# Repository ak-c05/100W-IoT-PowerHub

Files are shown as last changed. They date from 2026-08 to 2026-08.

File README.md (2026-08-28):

# 100W IoT Power Hub | ESP32-C3

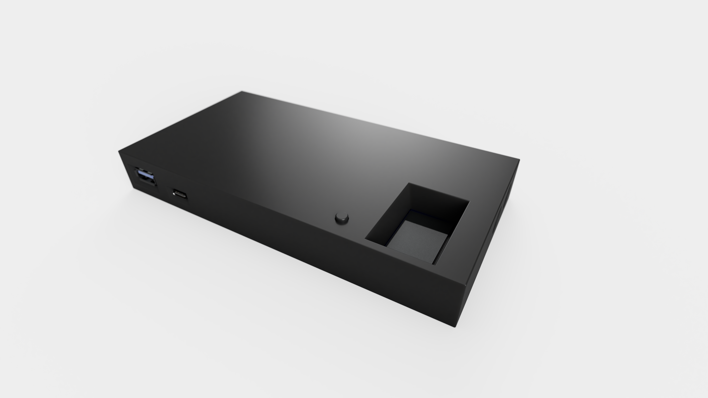
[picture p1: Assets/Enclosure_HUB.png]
Hero Render


A custom-engineered, dual-rail Power Delivery (PD) hub featuring hardware-level I2C telemetry, commercial DFM clamshell mechanics, and an asynchronous WebSocket control dashboard. 

---

## Mechanical Engineering (DFM)

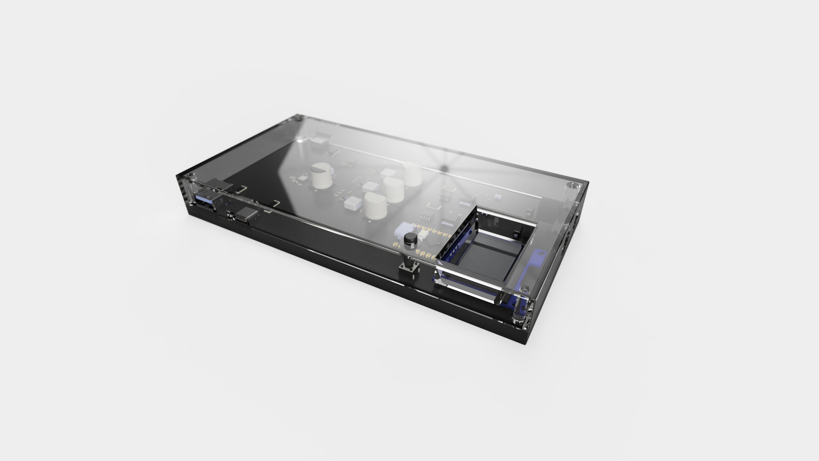
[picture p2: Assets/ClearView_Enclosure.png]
Internal Architecture


The enclosure is architected for a friction-fit prototyping phase, scaling to ultrasonic welding for mass production.
* **Non-Collision Assembly:** Designed with strict vertical U-channels for all I/O ports, eliminating plastic undercuts and allowing seamless top-down Z-axis assembly.
* **Interference Tolerancing:** Utilizes a modeled `0.05mm` press-pull lip-and-groove parting line to achieve a reliable friction fit without failure-prone snap hooks.
* **Kinematic Trapping:** The PCB is cradled by lower bosses and secured by mirrored upper retaining posts featuring a `0.2mm` rattle gap to guarantee closure without crushing the FR4 fiberglass.
* **Captive Actuation:** Features a custom 15mm "long-stem mushroom" plunger mechanism with strict 0.2mm clearance tolerances for the tactile UI switch.

---

## Electrical Architecture

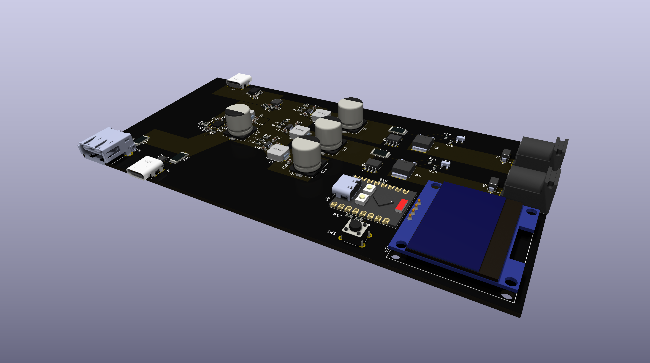
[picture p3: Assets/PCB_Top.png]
PCBA Render Top

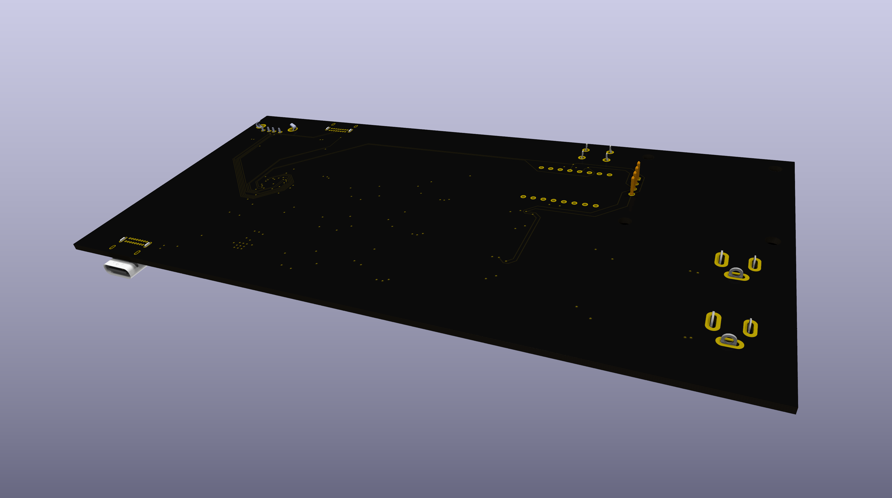
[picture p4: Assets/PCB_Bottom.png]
PCBA Render Bottom


Designed in KiCad 7/8, the motherboard isolates high-power delivery protocols from sensitive RF and logic components.
* **Dual-Rail Telemetry:** Utilizes two Texas Instruments INA219 ICs (I2C) for independent, high-speed monitoring of both the 12V Main and 9V PD lines.
* **Hardware PD Negotiation:** Integrates the autonomous SW3516 buck-boost controller for dedicated Type-C PD 3.0 protocol handshakes, offloading thermal and negotiation logic from the MCU.
* **RF Isolation:** Antenna routing and component placement are optimized to prevent the ESP32-C3's 2.4GHz radio from introducing jitter into the analog-to-digital current sensing pathways.

---

## Embedded Firmware & IoT

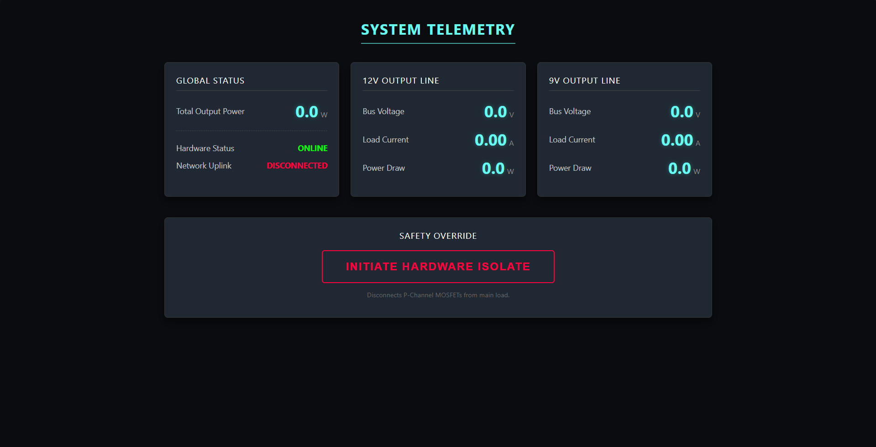
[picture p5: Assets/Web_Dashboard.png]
Web Dashboard


The C++ backend operates on a strict, non-blocking deterministic state machine, ensuring network handling never interrupts safety-critical hardware isolation.
* **Asynchronous WebSockets:** The ESP32 hosts a continuous WebSocket tunnel, pushing serialized JSON packets to the frontend only when clients are actively connected, saving CPU cycles.
* **PROGMEM Decoupling:** All HTML, CSS, and JavaScript assets are decoupled into an external `dashboard.h` file and stored in flash memory, preserving SRAM for runtime telemetry.
* **Hardware-Agnostic Graphics:** Drives a 1.3" SH1106 OLED using the U8g2 memory buffer, pushing mathematical frame geometry in single I2C blasts to prevent screen tearing.
* **Zero-Blocking Safety:** The 20-millisecond overcurrent protection polling loop runs independently of the network stack; physical hardware isolation always overrides remote UI commands.

---

## Future Roadmap
* Implementation of `WiFiManager` (Captive Portal) for dynamic AP provisioning, removing hardcoded network credentials from the master branch.

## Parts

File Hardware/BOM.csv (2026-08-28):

Reference | Qty | Value | Footprint | MANUFACTURER | MP
C1,C6,C12,C18,C22,C23 | 6 | 0.1uF | Capacitor_SMD:C_0603_1608Metric | Generic
C2 | 1 | 0.01uF | Capacitor_SMD:C_0603_1608Metric | Generic
C3 | 1 | 0.047uF | Capacitor_SMD:C_0603_1608Metric | Generic
C4,C5,C10,C11,C16,C17,C24 | 7 | 10uF | Capacitor_SMD:C_0603_1608Metric | Generic
C7,C8,C13,C14,C19,C20,C28,C29 | 8 | 22uF | Capacitor_SMD:C_0603_1608Metric | Generic
C9,C15,C21 | 3 | 470uF 35V | Capacitor_SMD:CP_Elec_10x10.5 | Generic
C25 | 1 | 1uF | Capacitor_SMD:C_0603_1608Metric | Generic
C26 | 1 | 2.2uF | Capacitor_SMD:C_0603_1608Metric | Generic
C27 | 1 | 10nF | Capacitor_SMD:C_0603_1608Metric | Generic
C30 | 1 | 220uF 35V | Capacitor_SMD:CP_Elec_10x10.5 | Generic
D1 | 1 | TVS(SMAJ13A) | DigitalHUB:TVS13(DIOM4325X250N) | Taiwan Semiconductor | SMAJ13A
D2 | 1 | TVS(SMAJ10A) | DigitalHUB:TVS10(DIOM4325X250N) | Taiwan Semiconductor | SMAJ10A
DS1 | 1 | OLED_128X64_1.3_I2C | DigitalHUB:LCD_OLED_128X64_1.3_I2C | UNIVERSAL-SOLDER Electronics Ltd | OLED 128x64 1.3"; I2C
J1,J4 | 2 | USB_C(USB4920-00-A_REVA) | DigitalHUB:USB_C(GCT_USB4920-00-A_REVA) | Global Connector Technology | USB4920-00-A
J2,J3 | 2 | DC_Plug(PJ-002AH) | DigitalHUB:DC_Plug(CUI_PJ-002AH) | CUI INC | PJ-002AH
J5 | 1 | USB_A(614004190021) | DigitalHUB:USB_A(614004190021) | Würth Elektronik | 614004190021
L1,L2,L3,L4 | 4 | 10uH | DigitalHUB:Inductor(WE-LHMI_7030) | Würth Elektronik | 74437346100
Q1,Q4 | 2 | MOSFET(AOD4185) | DigitalHUB:MOSFET(AOD4185) | Alpha & Omega | AOD4185
Q2,Q3 | 2 | NPN(MMBT3904) | DigitalHUB:NPN(MMBT3904) | Diotec Semiconductor | MMBT3904
Q5,Q6,Q7,Q8 | 4 | N-MOSFET(AON7400A) | DigitalHUB:TRANS_AON7407 | Alpha & Omega | AON7400A
R1,R9 | 2 | 140K | Resistor_SMD:R_0603_1608Metric | Generic
R2,R6,R7,R10,R15,R18,R21,R22,R23,R24,R25 | 11 | 10K | Resistor_SMD:R_0603_1608Metric | Generic
R3 | 1 | 301R | Resistor_SMD:R_0603_1608Metric | Generic
R4,R8,R11 | 3 | 100K | Resistor_SMD:R_0603_1608Metric | Generic
R5 | 1 | 191K | Resistor_SMD:R_0603_1608Metric | Generic
R12 | 1 | 75K | Resistor_SMD:R_0603_1608Metric | Generic
R13,R14 | 2 | 4.7K | Resistor_SMD:R_0603_1608Metric | Generic
R16,R17,R26,R27 | 4 | 0.01R 2W 1% | Resistor_SMD:R_2512_6332Metric | Generic
R19,R20 | 2 | 1K | Resistor_SMD:R_0603_1608Metric | Generic
SW1 | 1 | SW_Push | Button_Switch_THT:SW_PUSH_6mm_H5mm | Generic
SW2 | 1 | SW3516 | DigitalHUB:QFN-28_L4.0-W4.0-P0.40-BL-EP | Ismartware | SW3516
U1 | 1 | CH224K | Package_SO:SSOP-10-1EP_3.9x4.9mm_P1mm_EP2.1x3.3mm | WCH | CH224K
U2 | 1 | E_Fuse(TPS259827ONRGET) | DigitalHUB:E_Fuse(IC_TPS259827ONRGET) | Texas Instruments | TPS259827ONRGET
U3,U4,U5 | 3 | Buck(TPS54302DDCR) | DigitalHUB:Buck(SOT95P280X110-6N) | Texas Instruments | TPS54302DDCR
U6 | 1 | ESP32-C3_SUPERMINI_TH | DigitalHUB:MODULE_ESP32-C3_SUPERMINI_TH | Espressif Systems | ESP32-C3 SuperMini_TH
U7,U8 | 2 | Vtg_Sensor(INA219AIDR) | DigitalHUB:Vtg_Sensor(INA219AIDR) | Texas Instruments | INA219AIDR

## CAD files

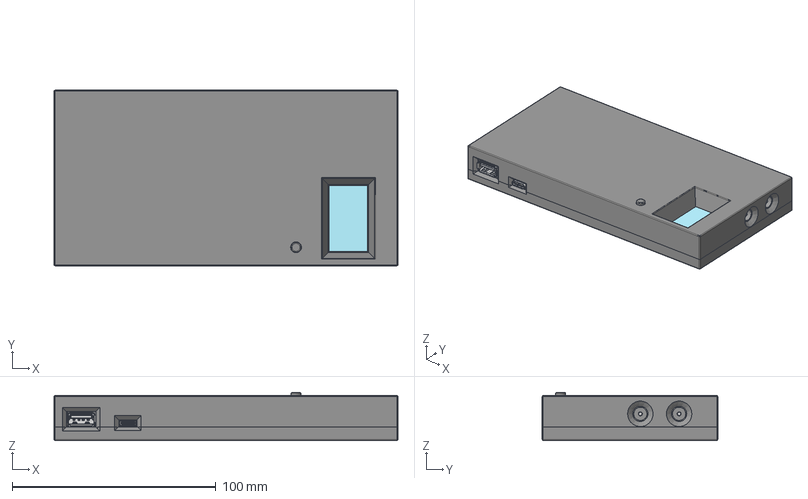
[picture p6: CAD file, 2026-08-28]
Mechanical/Digital_HUB_Master_Assembly_v2.step
168.8 x 86.1 x 23.6 mm
Bottom_Shell
R_2512_6332Metric x 4
C_0603_1608Metric x 26
SW_PUSH_6mm_h5mm_1
CP_Elec_10x105 x 4
pin x 4

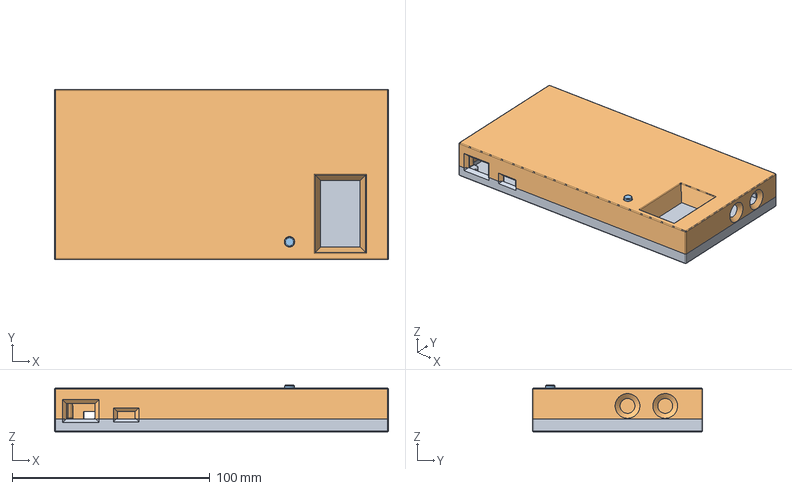
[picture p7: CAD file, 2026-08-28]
Mechanical/Digital_HUB_Plastics_Only_MFG_v2.step
168.8 x 86.1 x 23.6 mm

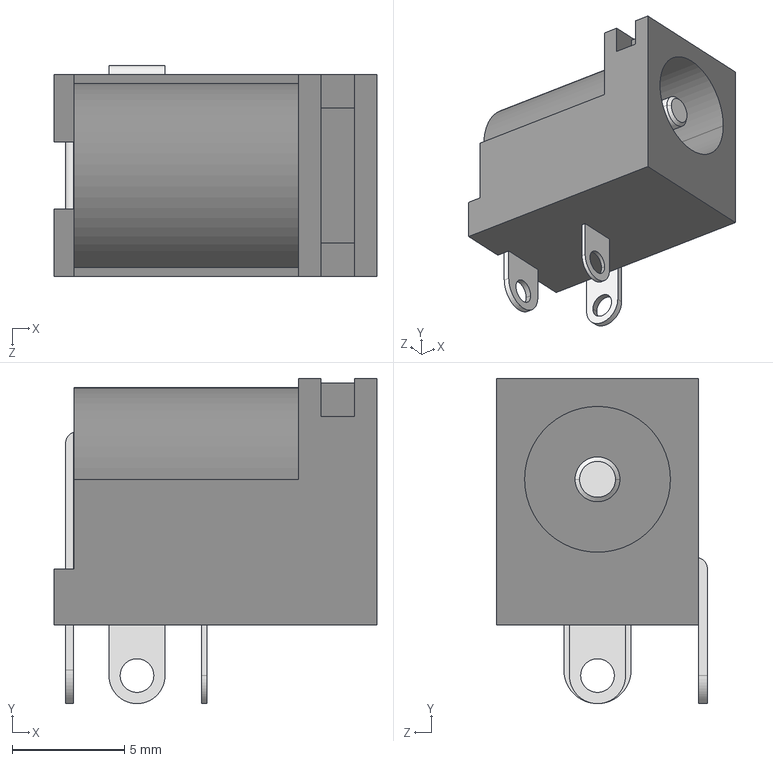
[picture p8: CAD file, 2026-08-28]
Hardware/Project_Libs/DigitalHUB_3D_Models/PJ-002AH.step
14.4 x 14.5 x 9.40 mm

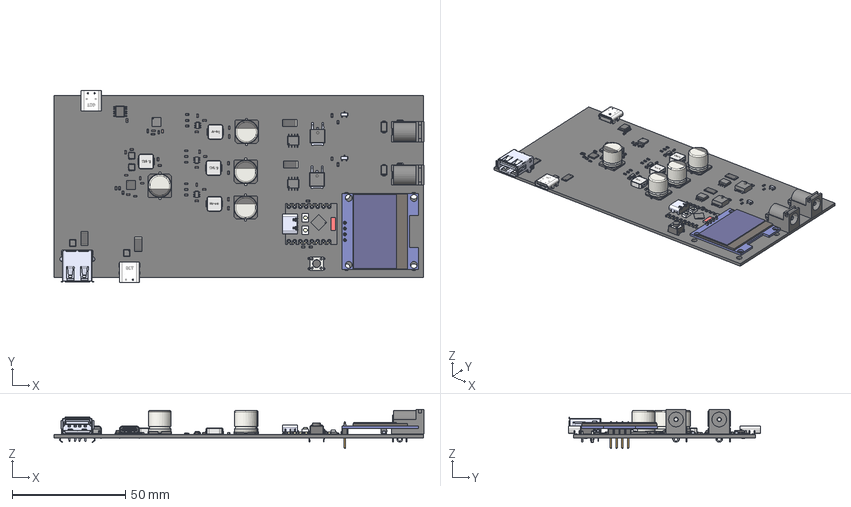
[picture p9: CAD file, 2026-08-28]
Mechanical/Digital_Hub_PCB.step
163.1 x 84.8 x 17.4 mm
R_0603_1608Metric x 23
R_2512_6332Metric x 4
C_0603_1608Metric x 26
SW_PUSH_6mm_h5mm
CP_Elec_10x105 x 4
CUI_DEVICES_PJ-002AH x 2
pin x 4
base x 4
AOD403 x 2
AON7522E x 4
MMBT3904--3DModel-STEP-711646 x 2
DDC6 x 3
SSOP-10-1EP_3.9x4.9mm_P1mm_EP2.1x3.3mm
PIN HEADER MALE 2.54MM P4
4 lü Lehim v2
Board c3mini
USB C
components (other)^ESP32-C3 SuperMini
1PGSMA110Z x 2
Cover
Internal Part
Pin
QFN-28_L4.0-W4.0-H0.9-P0.40-BL-EP
USB4920-00-A_PART1 x 2
USB4920-00-A_PART2 x 2
USB4920-00-A_PART3 x 2
USB4920-00-A_PART4 x 2
Body001 (Mirror #1) x 8
XY-plane x 24
X-axis x 24
RGE24
Digital_HUB_PCB

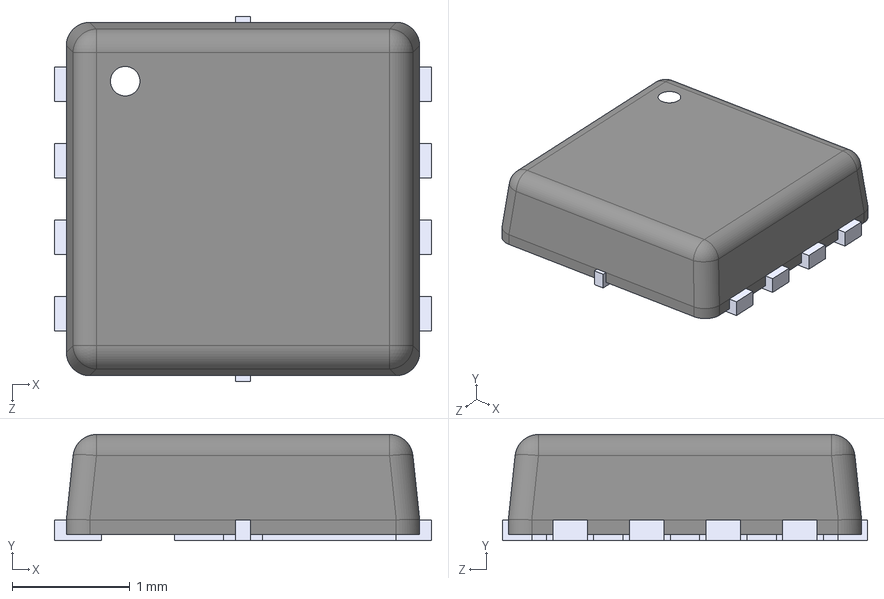
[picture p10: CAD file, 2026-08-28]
Hardware/Project_Libs/DigitalHUB_3D_Models/AON7400A.STEP
3.20 x 0.9 x 3.10 mm

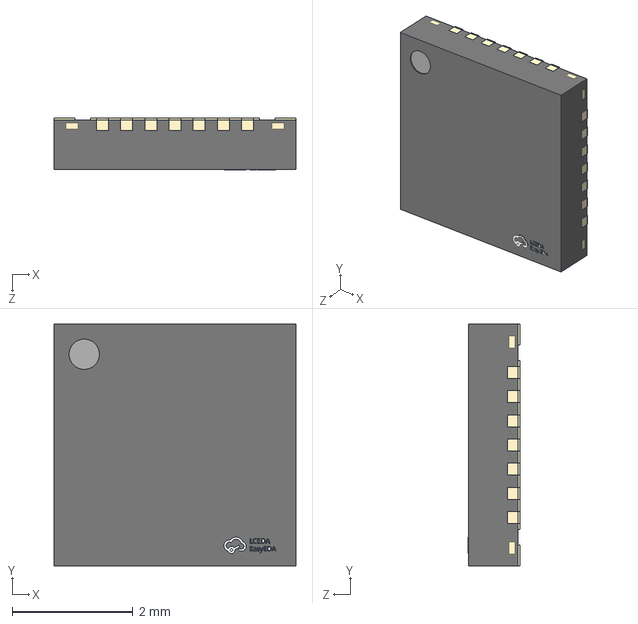
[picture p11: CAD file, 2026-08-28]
Hardware/Project_Libs/DigitalHUB_3D_Models/QFN-28_L4.0-W4.0-H0.9-P0.40-BL-EP.step
4.00 x 4.00 x 0.86 mm

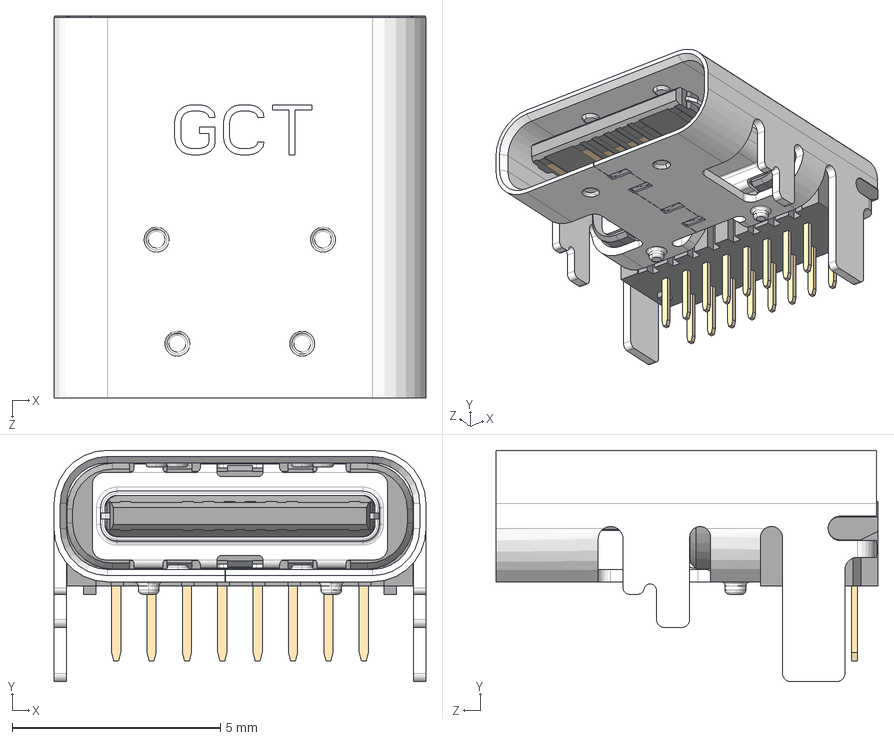
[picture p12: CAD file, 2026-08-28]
Hardware/Project_Libs/DigitalHUB_3D_Models/USB4920-00-A.stp
8.94 x 5.56 x 9.17 mm
USB4920-00-A_PART1
USB4920-00-A_PART2
USB4920-00-A_PART3
USB4920-00-A_PART4

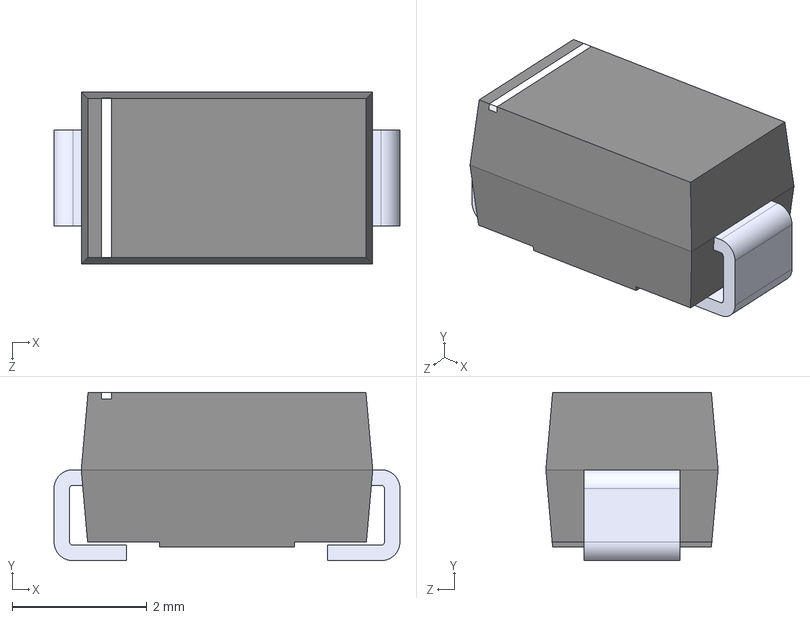
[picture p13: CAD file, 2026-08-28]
Hardware/Project_Libs/DigitalHUB_3D_Models/SMAJ10A.step
5.14 x 2.50 x 2.56 mm

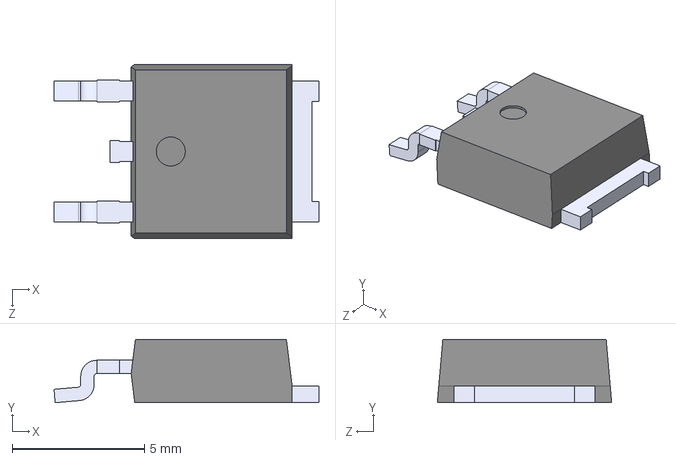
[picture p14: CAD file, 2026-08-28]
Hardware/Project_Libs/DigitalHUB_3D_Models/AOD4185.step
10.0 x 2.40 x 6.60 mm

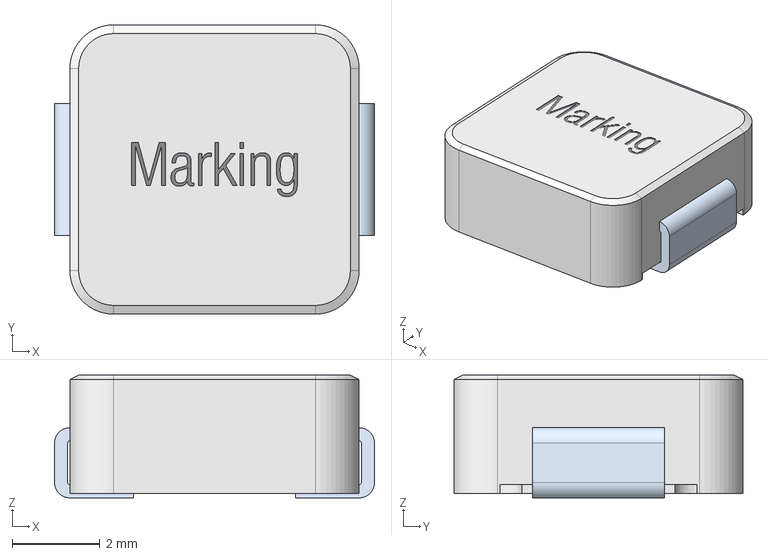
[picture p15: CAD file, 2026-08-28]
Hardware/Project_Libs/DigitalHUB_3D_Models/WE-LHMI_7030+%28rev1%29.stp
7.30 x 6.60 x 2.80 mm

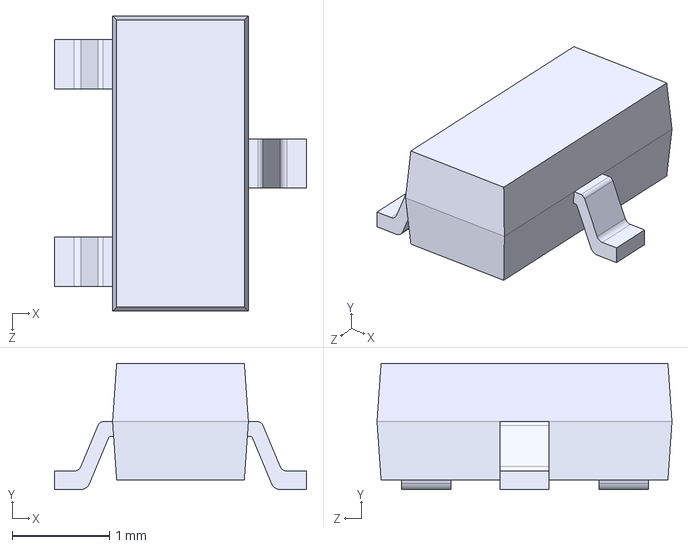
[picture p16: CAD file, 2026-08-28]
Hardware/Project_Libs/DigitalHUB_3D_Models/MMBT3904.step
2.60 x 1.30 x 3.04 mm

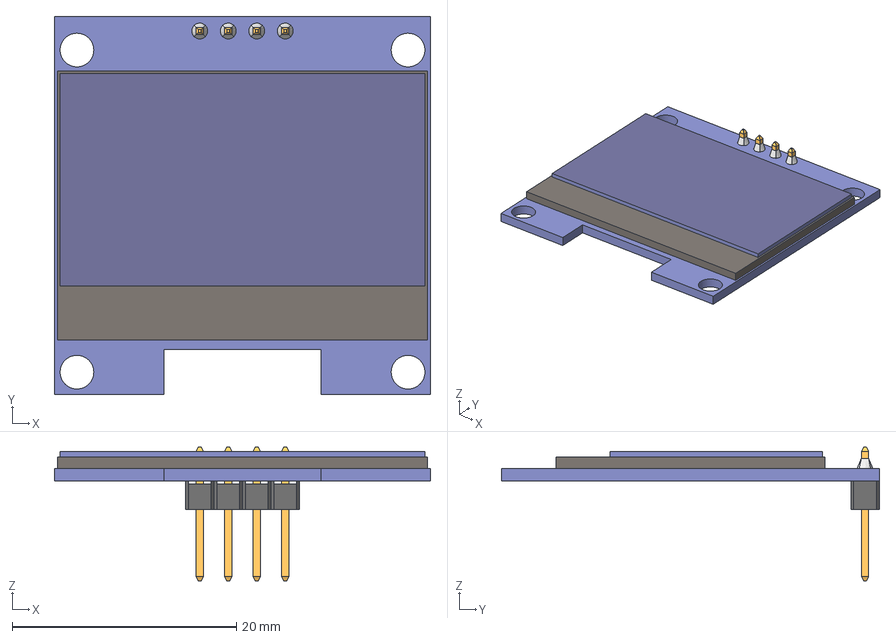
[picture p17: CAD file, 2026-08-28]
Hardware/Project_Libs/DigitalHUB_3D_Models/OLED I2C 1.3 Inch.step
33.5 x 33.7 x 11.9 mm
PIN HEADER MALE 2.54MM P4
4 lü Lehim v2

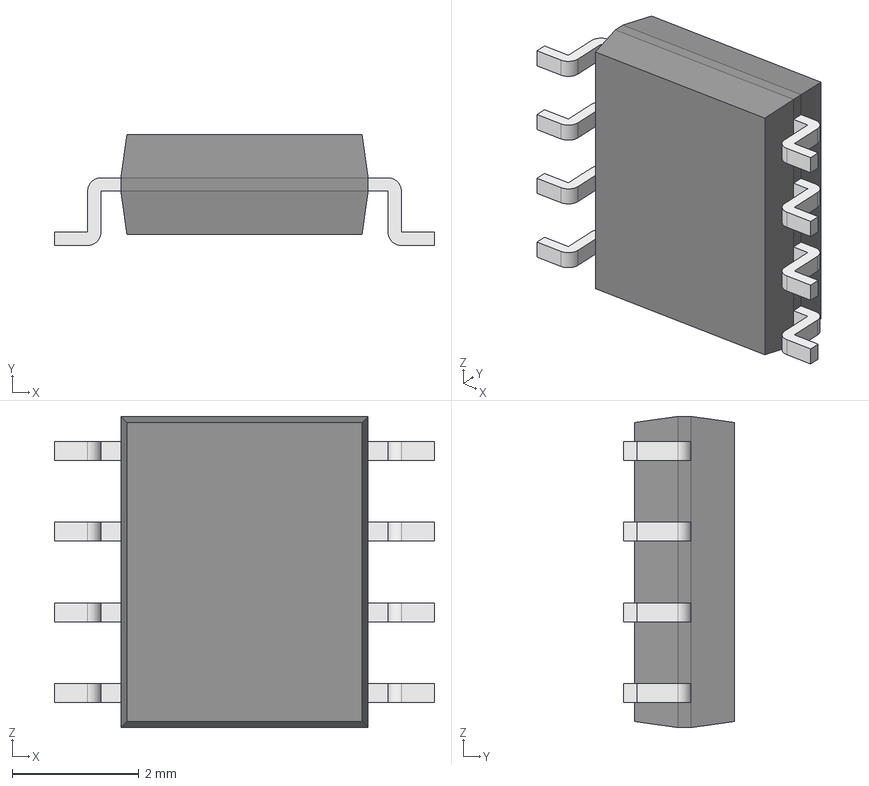
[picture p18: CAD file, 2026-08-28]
Hardware/Project_Libs/DigitalHUB_3D_Models/INA219AIDR.step
5.99 x 1.75 x 4.91 mm
Body001 (Mirror #1) x 4
XY-plane x 12
X-axis x 12

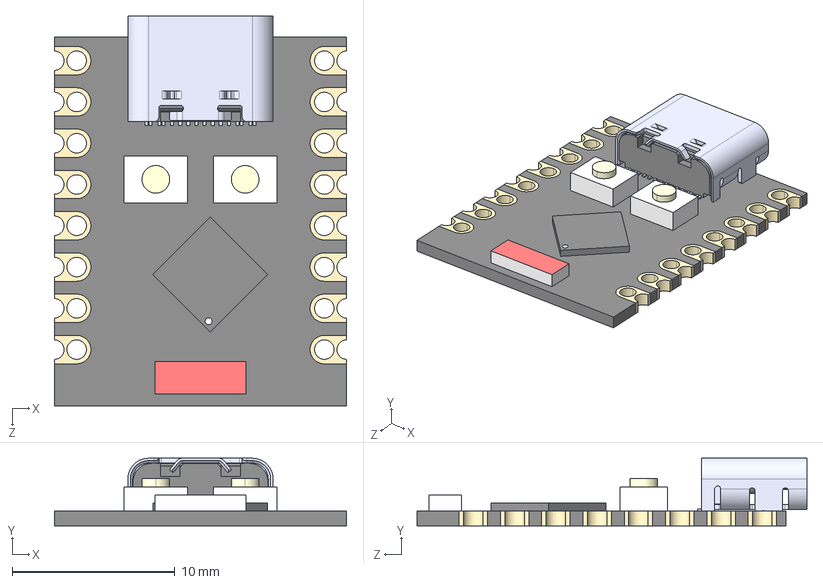
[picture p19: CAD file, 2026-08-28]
Hardware/Project_Libs/DigitalHUB_3D_Models/ESP32-C3_SUPERMINI_TH.step
18.0 x 4.16 x 24.0 mm
Board c3mini
USB C
components (other)^ESP32-C3 SuperMini

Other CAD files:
Hardware/Project_Libs/DigitalHUB_3D_Models/TPS259827ONRGET.step
Hardware/Project_Libs/DigitalHUB_3D_Models/614004190021.stp
Hardware/Project_Libs/DigitalHUB_3D_Models/TPS54302DDCR.step
Mechanical/Digital_HUB_Parametric_Archive_v2.f3z

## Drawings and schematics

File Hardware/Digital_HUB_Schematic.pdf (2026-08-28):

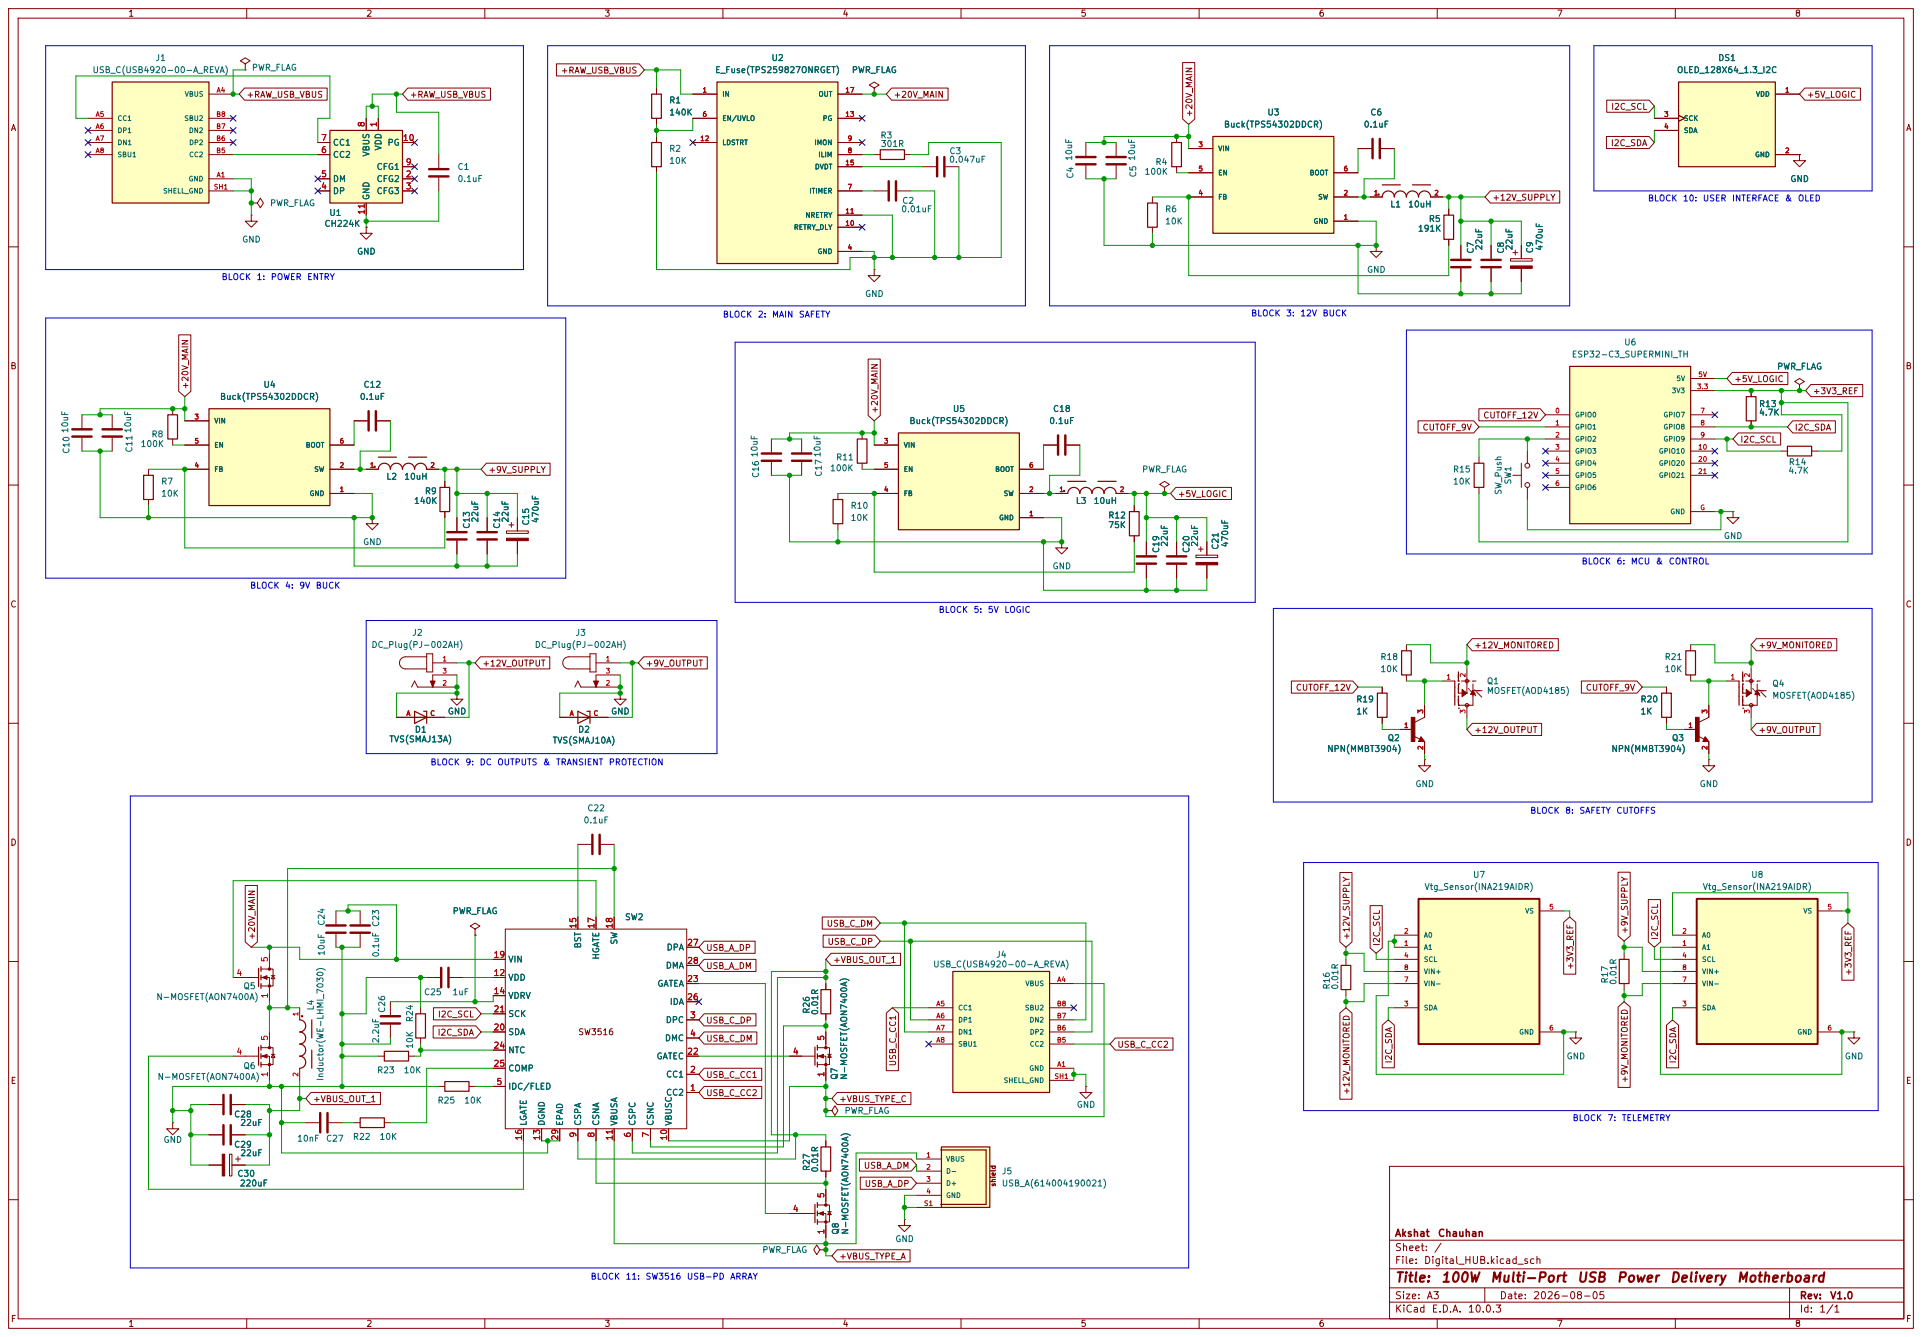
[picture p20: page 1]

BLOCK 6: MCU & CONTROL BLOCK 10: USER INTERFACE & OLED

IDA 26 DPA 27 DMA 28 EPAD 29 GND

USB_C_CC2 USB_C_CC1 BLOCK 9: DC OUTPUTS & TRANSIENT PROTECTION

IDA 26 DPA 27 DMA 28 EPAD 29

7 CSNA 8 CSPA 9 VBUSC 10 VBUSA 11

Akshat Chauhan
Sheet: /
File: Digital_HUB.kicad_sch
Title: 100W Multi-Port USB Power Delivery Motherboard

BLOCK 11: SW3516 USB-PD ARRAY

Size: A3 | Rev: V1.0 | F Date: 2026-08-05
KiCad E.D.A. 10.0.3 | Id: 1/1

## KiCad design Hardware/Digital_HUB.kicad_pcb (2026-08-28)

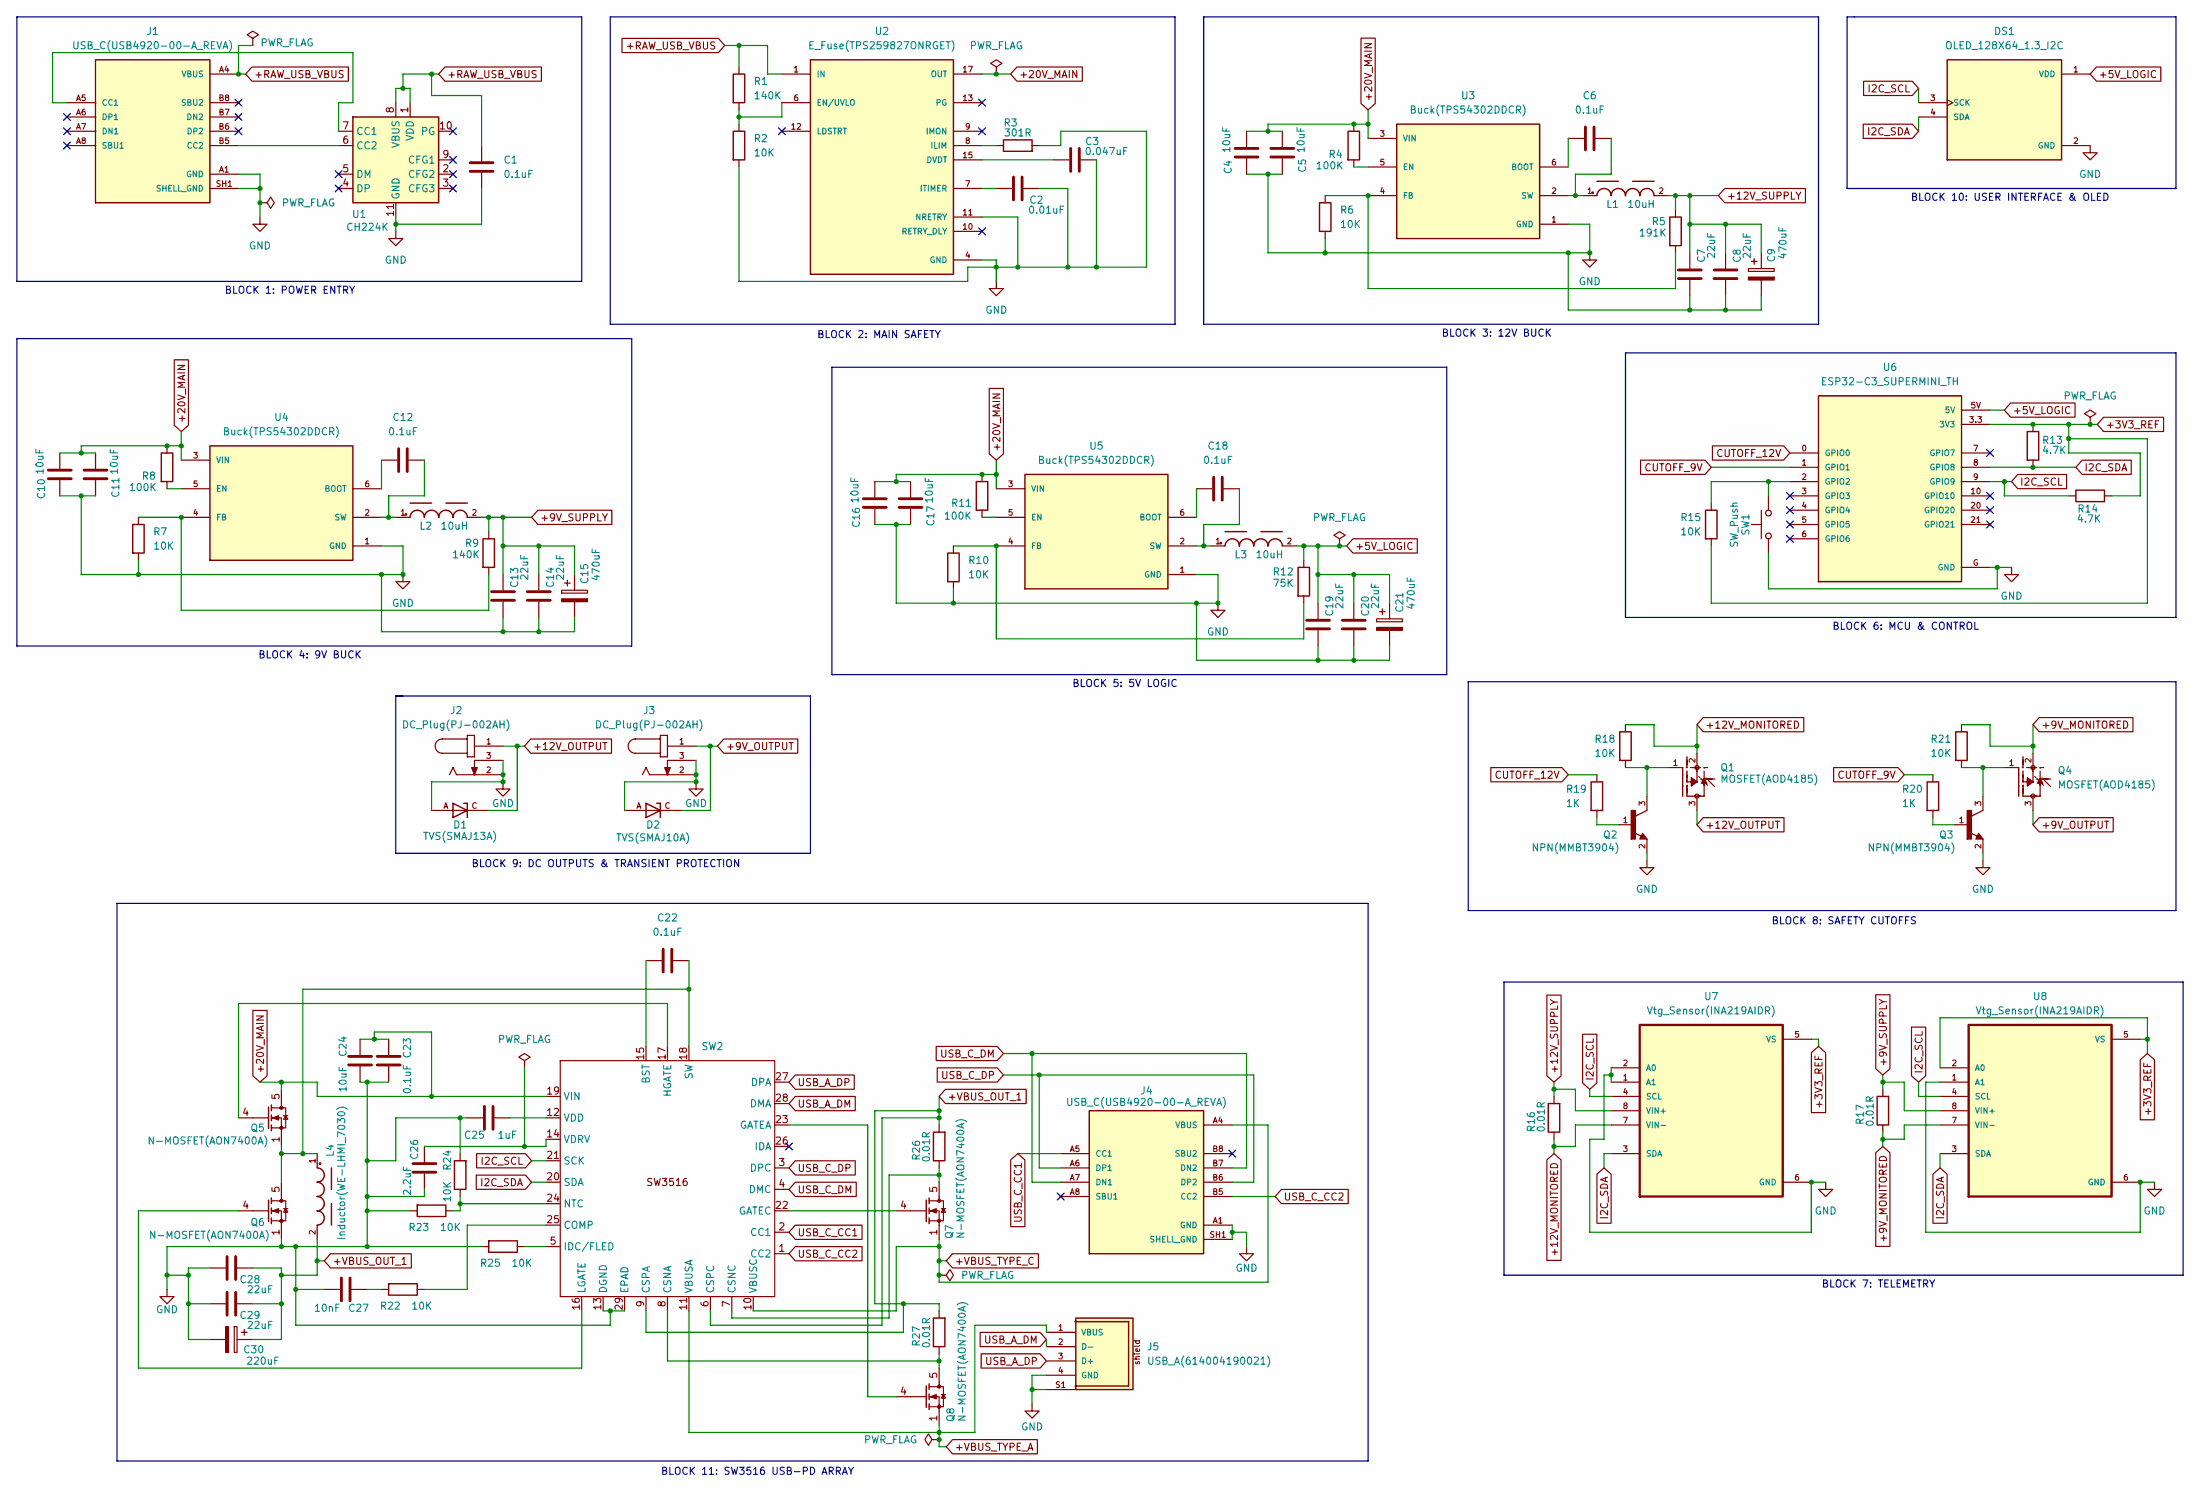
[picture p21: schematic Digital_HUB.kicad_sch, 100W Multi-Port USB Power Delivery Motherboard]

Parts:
C1, C6, C12, C18, C22, C23: 0.1uF; C_0603_1608Metric
C2: 0.01uF; C_0603_1608Metric
C3: 0.047uF; C_0603_1608Metric
C4, C5, C10, C11, C16, C17, C24: 10uF; C_0603_1608Metric
C7, C8, C13, C14, C19, C20, C28, C29: 22uF; C_0603_1608Metric
C9, C15, C21: 470uF; CP_Elec_10x10.5
C25: 1uF; C_0603_1608Metric
C26: 2.2uF; C_0603_1608Metric
C27: 10nF; C_0603_1608Metric
C30: 220uF; CP_Elec_10x10.5
D1: TVS(SMAJ13A); TVS13(DIOM4325X250N); PARTREV S2102
D2: TVS(SMAJ10A); TVS10(DIOM4325X250N); PARTREV S2102
DS1: OLED_128X64_1.3_I2C; LCD_OLED_128X64_1.3_I2C; PARTREV NA
J1, J4: USB_C(USB4920-00-A_REVA); USB_C(GCT_USB4920-00-A_REVA); PARTREV A
J2, J3: DC_Plug(PJ-002AH); DC_Plug(CUI_PJ-002AH)
J5: USB_A(614004190021)
L1, L2, L3: 10uH; Inductor(WE-LHMI_7030)
L4: Inductor(WE-LHMI_7030)
Q1, Q4: MOSFET(AOD4185)
Q2, Q3: NPN(MMBT3904); PARTREV 2025-06-30
Q5, Q6, Q7, Q8: N-MOSFET(AON7400A); TRANS_AON7407
R1, R9: 140K; R_0603_1608Metric
R2, R6, R7, R10, R15, R18, R21, R22, R23, R24, R25: 10K; R_0603_1608Metric
R3: 301R; R_0603_1608Metric
R4, R8, R11: 100K; R_0603_1608Metric
R5: 191K; R_0603_1608Metric
R12: 75K; R_0603_1608Metric
R13, R14: 4.7K; R_0603_1608Metric
R16, R17, R26, R27: 0.01R; R_2512_6332Metric
R19, R20: 1K; R_0603_1608Metric
SW1: SW_Push; SW_PUSH_6mm_H5mm
SW2: QFN-28_L4.0-W4.0-P0.40-BL-EP
U1: CH224K; SSOP-10-1EP_3.9x4.9mm_P1mm_EP2.1x3.3mm
U2: E_Fuse(TPS259827ONRGET); E_Fuse(IC_TPS259827ONRGET); PARTREV C
U3, U4, U5: Buck(TPS54302DDCR); Buck(SOT95P280X110-6N); PARTREV A
U6: ESP32-C3_SUPERMINI_TH; MODULE_ESP32-C3_SUPERMINI_TH
U7, U8: Vtg_Sensor(INA219AIDR)

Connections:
+3V3_REF: R13.1, R14.2, R15.2, U6.3.3 (3V3), U7.5 (VS), U8.2 (A0), U8.5 (VS)
+5V_LOGIC: C19.2, C20.2, C21.1, DS1.1 (VDD), L3.2, R12.1, U6.5V
+9V_MONITORED: Q4.2, R17.1, R21.1, U8.7 (VIN-)
+9V_OUTPUT: D2.C, J3.1, Q4.3
+9V_SUPPLY: C13.2, C14.2, C15.1, L2.2, R9.1, R17.2, U8.8 (VIN+)
+12V_MONITORED: Q1.2, R16.1, R18.1, U7.7 (VIN-)
+12V_OUTPUT: D1.C, J2.1, Q1.3
+12V_SUPPLY: C7.2, C8.2, C9.1, L1.2, R5.1, R16.2, U7.8 (VIN+)
+20V_MAIN: C4.2, C5.2, C10.2, C11.2, C16.2, C17.2, C23.1, C24.1, Q5.5 (D), Q5.6 (D), Q5.7 (D), Q5.8 (D), R4.1, R8.1, R11.1, SW2.19 (VIN), U2.17 (OUT), U2.18 (OUT), U2.19 (OUT), U2.20 (OUT), U2.21 (OUT), U2.22 (OUT), U2.23 (OUT), U2.24 (OUT), U3.3 (VIN), U4.3 (VIN), U5.3 (VIN)
+RAW_USB_VBUS: C1.1, J1.A4 (VBUS), J1.A9 (VBUS), J1.B4 (VBUS), J1.B9 (VBUS), R1.1, U1.1 (VDD), U1.8 (VBUS), U2.1 (IN), U2.2 (IN), U2.3 (IN), U2.16 (IN), U2.25 (IN)
+VBUS_OUT_1: C28.2, C29.2, C30.1, L4.2, R26.2, R27.2, SW2.6 (CSPC), SW2.9 (CSPA)
+VBUS_TYPE_A: J5.1 (VBUS), Q8.1 (S), Q8.2 (S), Q8.3 (S), SW2.11 (VBUSA)
+VBUS_TYPE_C: J4.A4 (VBUS), J4.A9 (VBUS), J4.B4 (VBUS), J4.B9 (VBUS), Q7.1 (S), Q7.2 (S), Q7.3 (S), SW2.10 (VBUSC)
CUTOFF_9V: R20.1, U6.1 (GPIO1)
CUTOFF_12V: R19.1, U6.0 (GPIO0)
GND: C1.2, C2.2, C3.2, C4.1, C5.1, C7.1, C8.1, C9.2, C10.1, C11.1, C13.1, C14.1, C15.2, C16.1, C17.1, C19.1, C20.1, C21.2, C23.2, C24.2, C25.1, C26.2, C27.2, C28.1, C29.1, C30.2, D1.A, D2.A, DS1.2 (GND), J1.A1 (GND), J1.A12 (GND), J1.B1 (GND), J1.B12 (GND), J1.SH1 (SHELL_GND), J1.SH2 (SHELL_GND), J1.SH3 (SHELL_GND), J1.SH4 (SHELL_GND), J2.2, J2.3, J3.2, J3.3, J4.A1 (GND), J4.A12 (GND), J4.B1 (GND), J4.B12 (GND), J4.SH1 (SHELL_GND), J4.SH2 (SHELL_GND), J4.SH3 (SHELL_GND), J4.SH4 (SHELL_GND), J5.4 (GND), J5.S1, J5.S2, Q2.2, Q3.2, Q6.1 (S), Q6.2 (S), Q6.3 (S), R2.2, R3.2, R6.2, R7.2, R10.2, R23.2, R24.2, R25.2, SW1.1, SW2.13 (DGND), SW2.29 (EPAD), U1.11 (GND), U2.4 (GND), U2.5 (GND), U2.11 (NRETRY), U2.14 (GND), U2.26 (GND), U3.1 (GND), U4.1 (GND), U5.1 (GND), U6.G (GND), U7.1 (A1), U7.2 (A0), U7.6 (GND), U8.1 (A1), U8.6 (GND)
I2C_SCL: DS1.3 (SCK), R14.1, SW2.21 (SCK), U6.9 (GPIO9), U7.4 (SCL), U8.4 (SCL)
I2C_SDA: DS1.4 (SDA), R13.2, SW2.20 (SDA), U6.8 (GPIO8), U7.3 (SDA), U8.3 (SDA)
unnamed: C27.1, R22.2
unnamed: J1.A5 (CC1), U1.7 (CC1)
unnamed: J1.B5 (CC2), U1.6 (CC2)
unnamed: Q1.1, Q2.3, R18.2
unnamed: Q2.1, R19.2
unnamed: Q3.1, R20.2
unnamed: Q3.3, Q4.1, R21.2
unnamed: Q5.4 (G), SW2.17 (HGATE)
unnamed: Q6.4 (G), SW2.16 (LGATE)
unnamed: Q7.4 (G), SW2.22 (GATEC)
unnamed: Q8.4 (G), SW2.23 (GATEA)
unnamed: C22.1, SW2.15 (BST)
unnamed: R22.1, SW2.25 (COMP)
unnamed: Q8.5 (D), Q8.6 (D), Q8.7 (D), Q8.8 (D), R27.1, SW2.8 (CSNA)
unnamed: Q7.5 (D), Q7.6 (D), Q7.7 (D), Q7.8 (D), R26.1, SW2.7 (CSNC)
unnamed: R25.1, SW2.5 (IDC/FLED)
unnamed: R23.1, R24.1, SW2.24 (NTC)
unnamed: C22.2, L4.1, Q5.1 (S), Q5.2 (S), Q5.3 (S), Q6.5 (D), Q6.6 (D), Q6.7 (D), Q6.8 (D), SW2.18 (SW)
unnamed: C25.2, SW2.12 (VDD)
unnamed: C26.1, SW2.14 (VDRV)
unnamed: C3.1, U2.15 (DVDT)
unnamed: R1.2, R2.1, U2.6 (EN/UVLO)
unnamed: R3.1, U2.8 (ILIM)
unnamed: C2.1, U2.7 (ITIMER)
unnamed: C6.1, U3.6 (BOOT)
unnamed: R4.2, U3.5 (EN)
unnamed: R5.2, R6.1, U3.4 (FB)
unnamed: C6.2, L1.1, U3.2 (SW)
unnamed: C12.1, U4.6 (BOOT)
unnamed: R8.2, U4.5 (EN)
unnamed: R7.1, R9.2, U4.4 (FB)
unnamed: C12.2, L2.1, U4.2 (SW)
unnamed: C18.1, U5.6 (BOOT)
unnamed: R11.2, U5.5 (EN)
unnamed: R10.1, R12.2, U5.4 (FB)
unnamed: C18.2, L3.1, U5.2 (SW)
unnamed: R15.1, SW1.2, U6.2 (GPIO2)
USB_A_DM: J5.2 (D-), SW2.28 (DMA)
USB_A_DP: J5.3 (D+), SW2.27 (DPA)
USB_C_CC1: J4.A5 (CC1), SW2.2 (CC1)
USB_C_CC2: J4.B5 (CC2), SW2.1 (CC2)
USB_C_DM: J4.A7 (DN1), J4.B7 (DN2), SW2.4 (DMC)
USB_C_DP: J4.A6 (DP1), J4.B6 (DP2), SW2.3 (DPC)

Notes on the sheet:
BLOCK 9: DC OUTPUTS & TRANSIENT PROTECTION
BLOCK 8: SAFETY CUTOFFS
BLOCK 1: POWER ENTRY
BLOCK 2: MAIN SAFETY
BLOCK 3: 12V BUCK
BLOCK 11: SW3516 USB-PD ARRAY
BLOCK 10: USER INTERFACE & OLED
BLOCK 7: TELEMETRY
BLOCK 4: 9V BUCK
BLOCK 5: 5V LOGIC
BLOCK 6: MCU & CONTROL

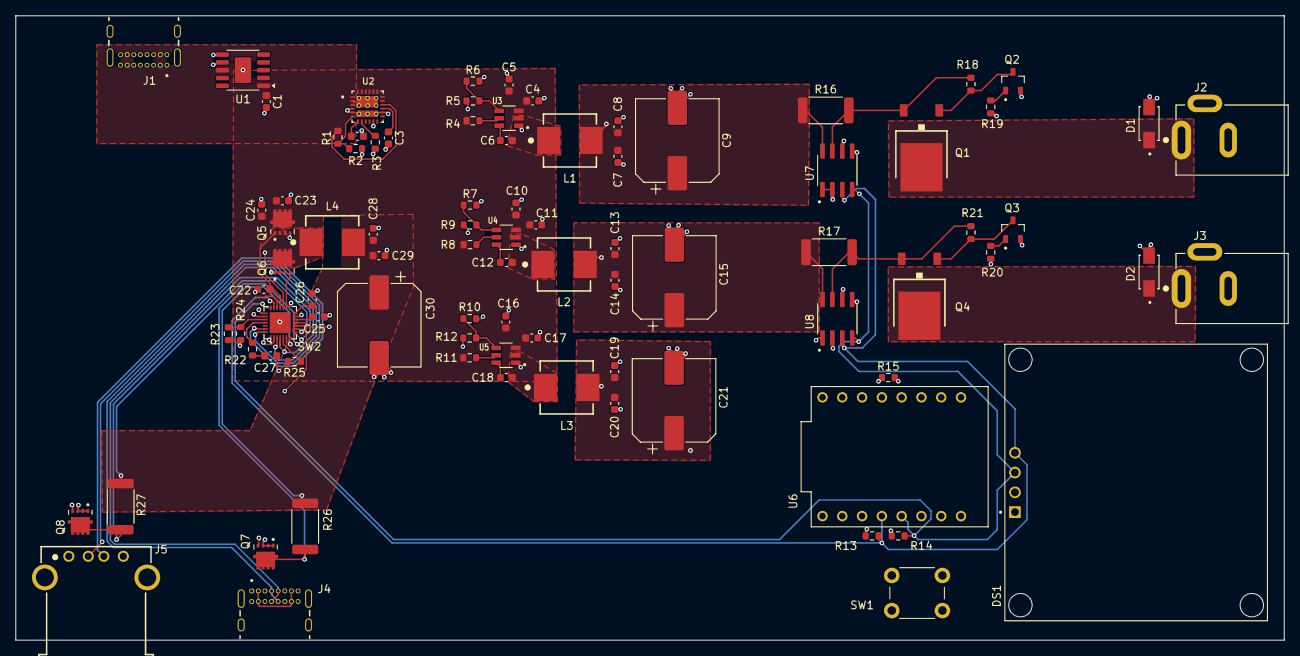
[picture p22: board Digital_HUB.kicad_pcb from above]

Board: 4 copper layers, 162.8 x 80.1 mm, 87 parts (0 on the bottom side), 61 nets.

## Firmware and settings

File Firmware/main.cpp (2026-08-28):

/**
 * @file      100W_IoT_PowerHub.ino
 * @brief     Firmware for ESP32-C3 Super Mini Power Delivery Motherboard
 * @hardware  ESP32-C3, 2x INA219, 1x SW3516, 1.3" SH1106 OLED, P-Channel MOSFETs
 * @notes     I2C mapped to GPIO 8 (SDA), GPIO 9 (SCL).
 *            OLED address shifted to 0x3D to avoid SW3516 bus collision.
 */

#include <Wire.h>
#include <WiFi.h>
#include <U8g2lib.h>
#include <INA219.h>
#include <ESPAsyncWebServer.h>
#include <ArduinoJson.h>
#include "dashboard.h"

const char *ssid = "YOUR_WIFI_SSID";
const char *password = "YOUR_WIFI_PASSWORD";

#define I2C_SDA_PIN 8
#define I2C_SCL_PIN 9
#define UI_BUTTON_PIN 2 // External 10k pull-up populated on PCB

// P-Channel MOSFET Gates (Active LOW)
#define GATE_12V_PIN 3
#define GATE_9V_PIN 4

#define SW3516_I2C_ADDRESS 0x3C
#define OLED_I2C_ADDRESS 0x3D 

U8G2_SH1106_128X64_NONAME_F_HW_I2C display(U8G2_R0, U8X8_PIN_NONE);
INA219 ina219_12V(0x40);
INA219 ina219_9V(0x41);

AsyncWebServer server(80);
AsyncWebSocket ws("/ws");

const float MAX_CURRENT_mA = 5000.0; 
const int SENSOR_POLL_RATE = 20;     
const int SW3516_POLL_RATE = 100;    
const int OLED_REFRESH_RATE = 250;   
const int WEB_PUSH_RATE = 500;       
const int DEBOUNCE_DELAY = 150;      

struct PowerData {
    float voltage_V;
    float current_mA;
    float power_W;
};

struct PDProtocolData {
    float negotiated_V;
    float negotiated_A;
    String active_protocol;
};

PowerData rail12V = {0, 0, 0};
PowerData rail9V = {0, 0, 0};
PDProtocolData sw3516_port = {0, 0, "SCANNING..."};

volatile int uiState = 0;
volatile unsigned long lastButtonTime = 0;
bool isFaultTripped = false;
bool isRemoteKilled = false;

unsigned long lastSensorRead = 0;
unsigned long lastSW3516Read = 0;
unsigned long lastOledUpdate = 0;
unsigned long lastWebPush = 0;

void IRAM_ATTR handleButtonPress() {
    unsigned long currentTime = millis();
    if ((currentTime - lastButtonTime) > DEBOUNCE_DELAY) {
        if (!isFaultTripped) {
            uiState = (uiState + 1) % 3;
        }
        lastButtonTime = currentTime;
    }
}

void onEvent(AsyncWebSocket *server, AsyncWebSocketClient *client, AwsEventType type, void *arg, uint8_t *data, size_t len) {
    if (type == WS_EVT_DATA) {
        String message = "";
        for (size_t i = 0; i < len; i++) {
            message += (char)data[i];
        }

        if (message == "KILL") {
            isRemoteKilled = !isRemoteKilled;
            if (isRemoteKilled) {
                digitalWrite(GATE_12V_PIN, HIGH);
                digitalWrite(GATE_9V_PIN, HIGH);  
            } else {
                if (!isFaultTripped) {
                    digitalWrite(GATE_12V_PIN, LOW);
                    digitalWrite(GATE_9V_PIN, LOW);
                }
            }
        }
    }
}

void setup() {
    pinMode(GATE_12V_PIN, OUTPUT);
    pinMode(GATE_9V_PIN, OUTPUT);
    digitalWrite(GATE_12V_PIN, HIGH);
    digitalWrite(GATE_9V_PIN, HIGH);

    pinMode(UI_BUTTON_PIN, INPUT);
    attachInterrupt(digitalPinToInterrupt(UI_BUTTON_PIN), handleButtonPress, FALLING);

    Wire.begin(I2C_SDA_PIN, I2C_SCL_PIN);
    Wire.setClock(400000);

    display.setI2CAddress(OLED_I2C_ADDRESS << 1);
    display.begin();
    display.setBusClock(400000);

    if (!ina219_12V.begin() || !ina219_9V.begin()) {
        displaySystemError("INA219 INIT FAIL");
        while (1) {
            delay(10);
        }
    }

    WiFi.mode(WIFI_STA);
    WiFi.begin(ssid, password);

    display.clearBuffer();
    display.setFont(u8g2_font_helvB08_tr);
    display.drawStr(10, 30, "CONNECTING WIFI...");
    display.sendBuffer();

    while (WiFi.status() != WL_CONNECTED) {
        delay(500);
    }

    server.on("/", HTTP_GET, [](AsyncWebServerRequest *request) { 
        request->send_P(200, "text/html", index_html); 
    });

    ws.onEvent(onEvent);
    server.addHandler(&ws);
    server.begin();

    digitalWrite(GATE_12V_PIN, LOW);
    digitalWrite(GATE_9V_PIN, LOW);
}

void loop() {
    unsigned long currentMillis = millis();

    ws.cleanupClients();

    if (currentMillis - lastSensorRead >= SENSOR_POLL_RATE) {
        lastSensorRead = currentMillis;
        updateTelemetry();
        executeSafetyCheck();
    }

    if (currentMillis - lastSW3516Read >= SW3516_POLL_RATE) {
        lastSW3516Read = currentMillis;
        pollSW3516Telemetry();
    }

    if (currentMillis - lastWebPush >= WEB_PUSH_RATE) {
        lastWebPush = currentMillis;
        pushDataToWeb();
    }

    if (currentMillis - lastOledUpdate >= OLED_REFRESH_RATE) {
        lastOledUpdate = currentMillis;
        renderOLED();
    }
}

void updateTelemetry() {
    rail12V.voltage_V = ina219_12V.getBusVoltage_V();
    rail12V.current_mA = ina219_12V.getCurrent_mA();
    rail12V.power_W = (rail12V.voltage_V * rail12V.current_mA) / 1000.0;

    rail9V.voltage_V = ina219_9V.getBusVoltage_V();
    rail9V.current_mA = ina219_9V.getCurrent_mA();
    rail9V.power_W = (rail9V.voltage_V * rail9V.current_mA) / 1000.0;
}

void executeSafetyCheck() {
    if (rail12V.current_mA > MAX_CURRENT_mA || rail9V.current_mA > MAX_CURRENT_mA) {
        digitalWrite(GATE_12V_PIN, HIGH);
        digitalWrite(GATE_9V_PIN, HIGH);
        isFaultTripped = true;
    }
}

void pollSW3516Telemetry() {
    Wire.beginTransmission(SW3516_I2C_ADDRESS);
    if (Wire.endTransmission() == 0) {
        Wire.requestFrom(SW3516_I2C_ADDRESS, 2);
        if (Wire.available() >= 2) {
            byte highByte = Wire.read();
            byte lowByte = Wire.read();
            sw3516_port.negotiated_V = 20.0;
            sw3516_port.active_protocol = "PD3.0 100W";
        }
    }
}

void pushDataToWeb() {
    if (ws.count() > 0) {
        StaticJsonDocument<200> doc;
        doc["v12"] = rail12V.voltage_V;
        doc["a12"] = rail12V.current_mA / 1000.0;
        doc["w12"] = rail12V.power_W;
        doc["v9"] = rail9V.voltage_V;
        doc["a9"] = rail9V.current_mA / 1000.0;
        doc["w9"] = rail9V.power_W;

        String jsonString;
        serializeJson(doc, jsonString);
        ws.textAll(jsonString);
    }
}

void renderOLED() {
    display.clearBuffer();

    if (isFaultTripped) {
        drawFaultScreen();
    } else {
        switch (uiState) {
        case 0:
            drawOverviewScreen();
            break;
        case 1:
            drawRailScreen("12V RAIL", rail12V);
            break;
        case 2:
            drawPD_RailScreen("9V + SW3516", rail9V, sw3516_port);
            break;
        }
    }

    display.sendBuffer();
}

void drawOverviewScreen() {
    display.setDrawColor(1);
    display.drawBox(0, 0, 128, 14);
    display.setDrawColor(0);
    display.setFont(u8g2_font_helvB08_tr);
    display.drawStr(16, 11, "100W SYSTEM HUB");

    display.setDrawColor(1);
    display.setFont(u8g2_font_helvB18_tr);

    float totalW = rail12V.power_W + rail9V.power_W;
    char buffer[10];
    dtostrf(totalW, 4, 1, buffer);
    display.drawStr(20, 40, buffer);

    display.setFont(u8g2_font_helvB08_tr);
    display.drawStr(90, 40, "W");

    display.drawLine(0, 52, 128, 52);
    
    if (isRemoteKilled) {
        display.drawStr(0, 63, "STATUS: REMOTE KILL");
    } else {
        display.drawStr(0, 63, "IP: " + WiFi.localIP().toString());
    }
}

void drawRailScreen(const char *title, PowerData &rail) {
    display.setFont(u8g2_font_helvB08_tr);
    display.drawStr(0, 9, title);
    display.drawLine(0, 12, 128, 12);

    display.setFont(u8g2_font_helvB24_tn);
    char v_buf[8];
    dtostrf(rail.voltage_V, 4, 1, v_buf);
    display.drawStr(0, 42, v_buf);

    display.setFont(u8g2_font_helvB08_tr);
    display.drawStr(70, 42, "V");

    char sub_buf[10];
    dtostrf(rail.current_mA / 1000.0, 4, 2, sub_buf);
    display.drawStr(90, 26, sub_buf);
    display.drawStr(120, 26, "A");

    dtostrf(rail.power_W, 4, 1, sub_buf);
    display.drawStr(90, 42, sub_buf);
    display.drawStr(120, 42, "W");

    display.drawLine(0, 52, 128, 52);
    display.drawStr(0, 63, "                      [>]");
}

void drawPD_RailScreen(const char *title, PowerData &rail, PDProtocolData &pd) {
    drawRailScreen(title, rail);
    display.setDrawColor(0);
    display.drawBox(0, 53, 128, 11);
    display.setDrawColor(1);

    display.setFont(u8g2_font_helvB08_tr);
    display.setCursor(0, 63);
    display.print(pd.active_protocol);
    display.drawStr(110, 63, "[>]");
}

void drawFaultScreen() {
    display.setFont(u8g2_font_helvB14_tr);
    display.drawStr(10, 30, "OVERCURRENT");
    display.drawStr(30, 50, "FAULT");
    display.drawFrame(0, 0, 128, 64);
    display.drawFrame(1, 1, 126, 62);
}

void displaySystemError(const char *msg) {
    display.clearBuffer();
    display.setFont(u8g2_font_helvB08_tr);
    display.drawStr(0, 20, "SYSTEM HALTED:");
    display.drawStr(0, 40, msg);
    display.sendBuffer();
}
